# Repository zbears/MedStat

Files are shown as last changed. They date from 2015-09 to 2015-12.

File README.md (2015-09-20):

# MedStat
A wearable medical wristband

## Eagle Setup
In order to modify the cirucits in Eagle, clone the git repo then open Eagle. Go to Options->Directories and add the /circuits/libraries folder to your libraries path. Then add the /circuits folder to your projects path.

## Creating/Modifying Circuits
To create or modify a circuit, please create a separate branch from master. Go into the /circuits folder and create a directory whose name corresponds to the circuit you are creating. When you've finished creating the circuit, submit a pull request and have your circuit verified by one engineer. Once the circuit is verified, make the modifications to the main MedStat eagle project to include your circuit, submit another pull request to master, have one other engineer verify your circuit, then merge your branch with master. Do not delete your branch after merging with master.

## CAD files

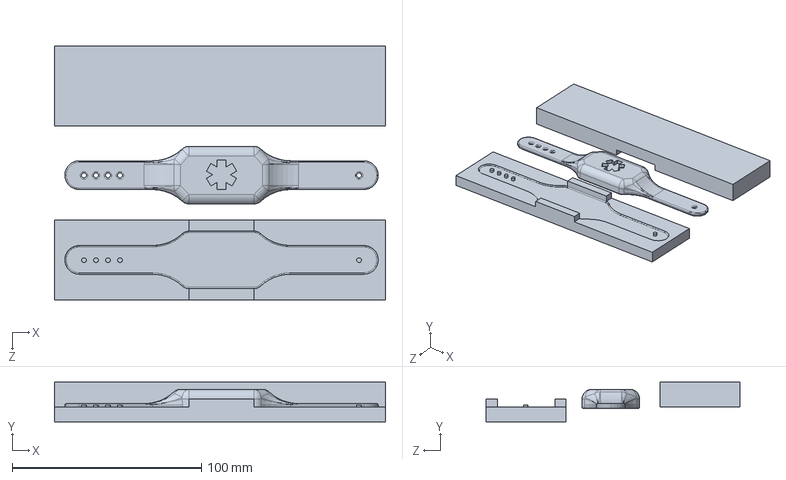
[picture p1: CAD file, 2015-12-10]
3d models/Wristband.SLDPRT
175.1 x 21.1 x 134.4 mm

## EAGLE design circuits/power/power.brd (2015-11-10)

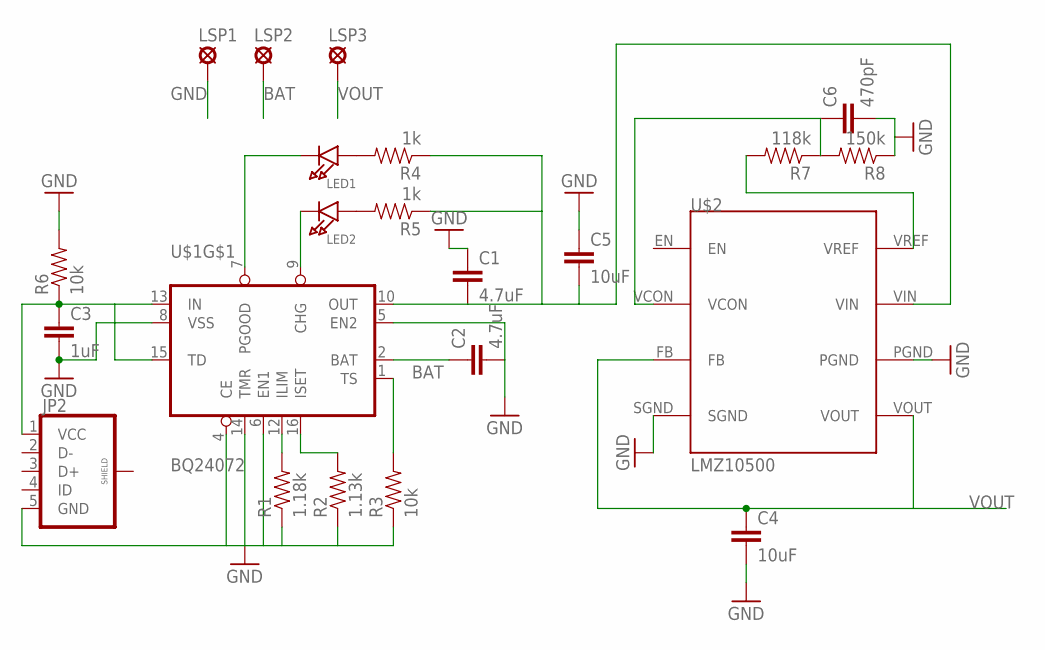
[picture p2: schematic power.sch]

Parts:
C1, C2: 4.7uF; 0603-CAP
C3: 1uF; 0603-CAP
C4, C5: 10uF; 0603-CAP
C6: 470pF; 0603-CAP
JP2: USB_MICROB_PLUG-SMT; MICRO-B-SMT
LED1, LED2: LED0603; CHIPLED_0603
LSP1, LSP2, LSP3: LSP10
R1: 1.18k; 0603-RES
R2: 1.13k; 0603-RES
R3, R6: 10k; 0603-RES
R4, R5: 1k; 0603-RES
R7: 118k; 0603-RES
R8: 150k; 0603-RES
U$1: BQ24072; S-PVQFN-N16
U$2: LMZ10500

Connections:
BAT: C2.1, LSP2.MP, U$1.2 (BAT)
GND: C1.1, C2.2, C3.2, C4.2, C5.1, C6.2, JP2.5 (GND), LSP1.MP, R1.1, R2.1, R3.1, R6.2, R8.1, U$1.4 (CE), U$1.5 (EN2), U$1.6 (EN1), U$1.8 (VSS), U$1.14 (TMR), U$2.PGND, U$2.SGND
unnamed: R7.2, U$2.VREF
unnamed: C6.1, R7.1, R8.2, U$2.VCON
unnamed: R1.2, U$1.12 (ILIM)
unnamed: R2.2, U$1.16 (ISET)
unnamed: R3.2, U$1.1 (TS)
unnamed: C1.2, C5.2, R4.1, R5.1, U$1.10 (OUT), U$2.VIN
unnamed: LED1.A, R4.2
unnamed: LED2.A, R5.2
unnamed: LED2.C, U$1.9 (CHG)
unnamed: LED1.C, U$1.7 (PGOOD)
unnamed: C3.1, JP2.1 (VCC), R6.1, U$1.13 (IN), U$1.15 (TD)
VOUT: C4.1, LSP3.MP, U$2.FB, U$2.VOUT

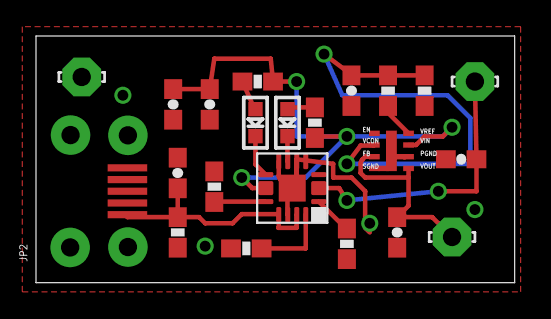
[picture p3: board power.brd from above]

Board: 2 copper layers, 26.6 x 13.7 mm, 22 parts (0 on the bottom side), 14 nets.

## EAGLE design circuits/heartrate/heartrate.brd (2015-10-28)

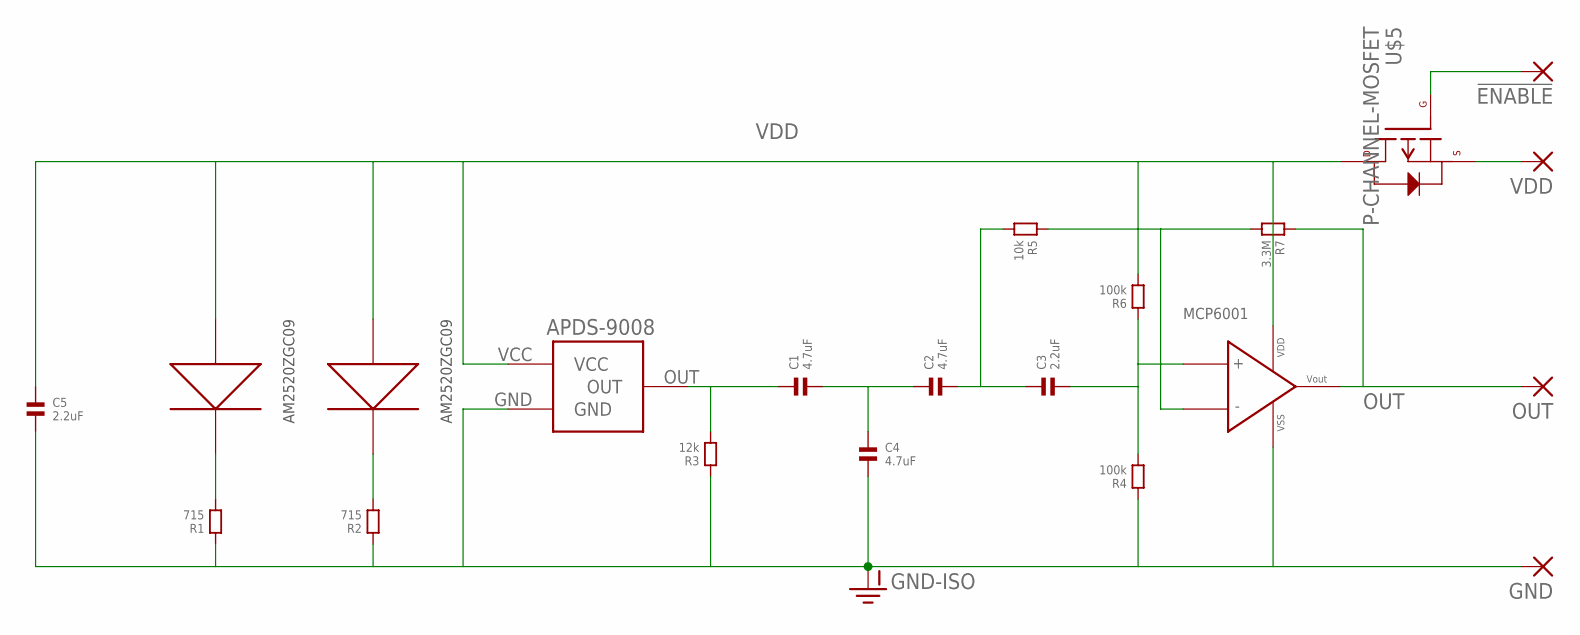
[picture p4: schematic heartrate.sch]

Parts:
!ENABLE: SMD2; SMD1,27-2,54
C1, C2, C4: 4.7uF; 0402
C3, C5: 2.2uF; 0402
GND: SMD2; SMD1,27-2,54
OUT: SMD2; SMD1,27-2,54
R1, R2: 715; 0402
R3: 12k; 0402
R4, R6: 100k; 0402
R5: 10k; 0402
R7: 3.3M; 0402
U$1, U$2: DSAH3717
U$3: APDS-9008
U$4: MCP6001; SOT23-5
U$5: P-CHANNEL-MOSFET; SOT23-3
VDD: SMD2; SMD1,27-2,54

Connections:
GND: C4.2, C5.2, GND.1, R1.1, R2.1, R3.1, R4.1, U$3.GND, U$4.VSS
unnamed: R1.2, U$1.G (GND)
unnamed: U$5.2 (S), VDD.1
unnamed: !ENABLE.1, U$5.1 (G)
unnamed: R2.2, U$2.G (GND)
unnamed: C1.1, R3.2, U$3.OUT
unnamed: C1.2, C2.1, C4.1
unnamed: C2.2, C3.1, R5.2
unnamed: C3.2, R4.2, R6.1, U$4.VIN+
unnamed: R5.1, R7.2, U$4.VIN-
OUT: OUT.1, R7.1, U$4.VOUT
VDD: C5.1, R6.2, U$1.V (VDD), U$2.V (VDD), U$3.VCC, U$4.VDD, U$5.3 (D)

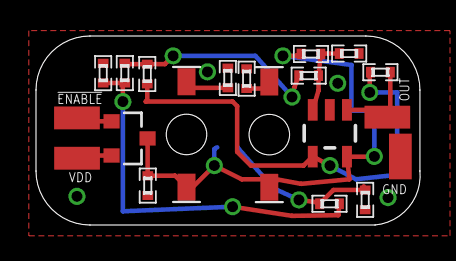
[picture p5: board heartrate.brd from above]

Board: 2 copper layers, 21.3 x 10.5 mm, 21 parts (1 on the bottom side), 12 nets.

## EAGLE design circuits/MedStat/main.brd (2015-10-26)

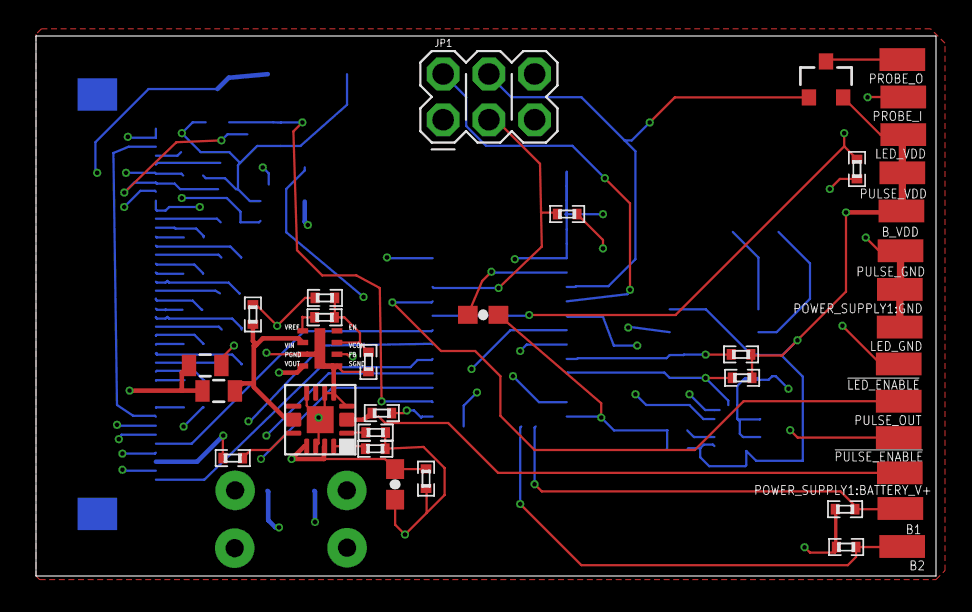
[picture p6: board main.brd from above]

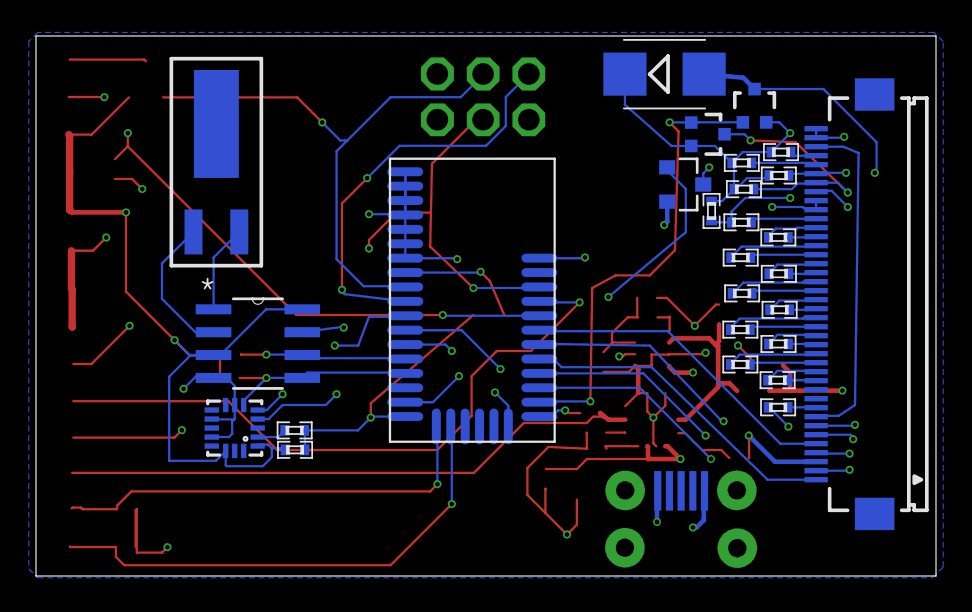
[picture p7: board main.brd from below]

Board: 4 copper layers, 50.0 x 30.0 mm, 65 parts (28 on the bottom side), 60 nets.

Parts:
!LED_ENABLE: SMD1,27-2,54
!PULSE_ENABLE: SMD1,27-2,54
B1, B2: SMD1,27-2,54
B_VDD: SMD1,27-2,54
C1: 1uF; 0603-CAP
C2: 0.1uF; 0402
C3: 4.7uF; 0402
EPAPER_DRIVER1:C1, EPAPER_DRIVER1:C2, EPAPER_DRIVER1:C3, EPAPER_DRIVER1:C4, EPAPER_DRIVER1:C5, EPAPER_DRIVER1:C6, EPAPER_DRIVER1:C7, EPAPER_DRIVER1:C8, EPAPER_DRIVER1:C9, EPAPER_DRIVER1:C10, EPAPER_DRIVER1:C12, EPAPER_DRIVER1:C13, EPAPER_DRIVER1:C14, EPAPER_DRIVER1:C15: 2.2uF; 0402
EPAPER_DRIVER1:C11: 1uF; 0402
EPAPER_DRIVER1:D2: B24013F; SMB
EPAPER_DRIVER1:Q1, EPAPER_DRIVER1:Q2: MOSFET-NCHANNEL2N7002PW; SOT323
EPAPER_DRIVER1:R1: 2k; 0402
EPAPER_DRIVER1:U$1: P-CHANNEL-MOSFET; SOT23-3
EPAPER_DRIVER1:X1: FH12-40S-0.5SH
JP1: 2X3_POGO
LED_GND: SMD1,27-2,54
LED_VDD: SMD1,27-2,54
POWER_SUPPLY1:BATTERY_V+, POWER_SUPPLY1:GND: SMD1,27-2,54
POWER_SUPPLY1:C1, POWER_SUPPLY1:C4: 4.7uF; 0402
POWER_SUPPLY1:C2, POWER_SUPPLY1:C3: 10uF; 0805
POWER_SUPPLY1:C6: 470pF; 0402
POWER_SUPPLY1:C7: 1uF; 0603-CAP
POWER_SUPPLY1:JP1: MICRO-B-SMT
POWER_SUPPLY1:R1: 1.18k; 0402
POWER_SUPPLY1:R2: 1.13k; 0402
POWER_SUPPLY1:R3, POWER_SUPPLY1:R4: 10k; 0402
POWER_SUPPLY1:R5: 150k; 0402
POWER_SUPPLY1:R6: 118k; 0402
POWER_SUPPLY1:U$1: BQ24072; S-PVQFN-N16
POWER_SUPPLY1:U$2: LMZ10500
PROBE_I: SMD1,27-2,54
PROBE_O: SMD1,27-2,54
PULSE_GND: SMD1,27-2,54
PULSE_OUT: SMD1,27-2,54
PULSE_VDD: SMD1,27-2,54
R1, R5, R6: 10k; 0402
R2, R3: 4.7k; 0402
R4: 1M; 0402
U1: BLE113-A
U2: MMA8452Q; QFN-16_0.5MM
U3: BQ32000DR; SOIC127P600X175-8N
U$1: P-CHANNEL-MOSFET; SOT23-3
Y1: CRYSTAL_CYL_2X6MM_SMT

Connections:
3.3V: B_VDD.1, C1.2, C3.1, EPAPER_DRIVER1:U$1.2, JP1.P$1, LED_VDD.1, POWER_SUPPLY1:C2.1, POWER_SUPPLY1:U$2.FB, POWER_SUPPLY1:U$2.VOUT, PULSE_VDD.1, R1.2, R2.2, R3.2, U1.AVDD, U1.DVDD, U2.1, U2.14, U3.3, U3.8, U$1.2
!RESET: JP1.P$3, R1.1, U1.RESET
EPAPER_DRIVER1:BORDER: EPAPER_DRIVER1:X1.8, EPAPER_DRIVER1:X1.38
EPAPER_DRIVER1:C11M: EPAPER_DRIVER1:C10.2, EPAPER_DRIVER1:X1.28
EPAPER_DRIVER1:C11P: EPAPER_DRIVER1:C10.1, EPAPER_DRIVER1:X1.29
EPAPER_DRIVER1:C12M: EPAPER_DRIVER1:C9.2, EPAPER_DRIVER1:X1.26
EPAPER_DRIVER1:C12P: EPAPER_DRIVER1:C9.1, EPAPER_DRIVER1:X1.27
EPAPER_DRIVER1:C13M: EPAPER_DRIVER1:C8.2, EPAPER_DRIVER1:X1.24
EPAPER_DRIVER1:C13P: EPAPER_DRIVER1:C8.1, EPAPER_DRIVER1:X1.25
EPAPER_DRIVER1:C14M: EPAPER_DRIVER1:C7.2, EPAPER_DRIVER1:X1.22
EPAPER_DRIVER1:C14P: EPAPER_DRIVER1:C7.1, EPAPER_DRIVER1:X1.23
EPAPER_DRIVER1:C15M: EPAPER_DRIVER1:C6.2, EPAPER_DRIVER1:X1.20
EPAPER_DRIVER1:C15P: EPAPER_DRIVER1:C6.1, EPAPER_DRIVER1:X1.21
EPAPER_DRIVER1:C16M: EPAPER_DRIVER1:C5.2, EPAPER_DRIVER1:X1.18
EPAPER_DRIVER1:C16P: EPAPER_DRIVER1:C5.1, EPAPER_DRIVER1:X1.19
EPAPER_DRIVER1:C21M: EPAPER_DRIVER1:C4.2, EPAPER_DRIVER1:X1.16
EPAPER_DRIVER1:C21P: EPAPER_DRIVER1:C4.1, EPAPER_DRIVER1:X1.17
EPAPER_DRIVER1:C31M: EPAPER_DRIVER1:C3.2, EPAPER_DRIVER1:X1.14
EPAPER_DRIVER1:C31P: EPAPER_DRIVER1:C3.1, EPAPER_DRIVER1:X1.15
EPAPER_DRIVER1:C32M: EPAPER_DRIVER1:C2.2, EPAPER_DRIVER1:X1.12
EPAPER_DRIVER1:C32P: EPAPER_DRIVER1:C2.1, EPAPER_DRIVER1:X1.13
EPAPER_DRIVER1:E_VDD: EPAPER_DRIVER1:U$1.3, EPAPER_DRIVER1:X1.31, EPAPER_DRIVER1:X1.32
EPAPER_DRIVER1:VCL: EPAPER_DRIVER1:C1.2, EPAPER_DRIVER1:X1.9
EPAPER_DRIVER1:VCOM_DRIVER: EPAPER_DRIVER1:R1.2, EPAPER_DRIVER1:X1.30
EPAPER_DRIVER1:VDH: EPAPER_DRIVER1:C14.2, EPAPER_DRIVER1:X1.36
EPAPER_DRIVER1:VDL: EPAPER_DRIVER1:C15.2, EPAPER_DRIVER1:X1.37
EPAPER_DRIVER1:VGH: EPAPER_DRIVER1:C12.2, EPAPER_DRIVER1:Q2.3, EPAPER_DRIVER1:X1.34
EPAPER_DRIVER1:VGL: EPAPER_DRIVER1:C13.2, EPAPER_DRIVER1:D2.A, EPAPER_DRIVER1:Q1.3, EPAPER_DRIVER1:X1.35
EPAPER_DRIVER1:VST: EPAPER_DRIVER1:C11.2, EPAPER_DRIVER1:R1.1, EPAPER_DRIVER1:X1.39, EPAPER_DRIVER1:X1.40
GND: C1.1, C2.1, C3.2, EPAPER_DRIVER1:C1.1, EPAPER_DRIVER1:C11.1, EPAPER_DRIVER1:C12.1, EPAPER_DRIVER1:C13.1, EPAPER_DRIVER1:C14.1, EPAPER_DRIVER1:C15.1, EPAPER_DRIVER1:D2.C, EPAPER_DRIVER1:Q1.2, EPAPER_DRIVER1:Q2.2, EPAPER_DRIVER1:X1.3, EPAPER_DRIVER1:X1.33, JP1.P$5, LED_GND.1, POWER_SUPPLY1:C1.1, POWER_SUPPLY1:C2.2, POWER_SUPPLY1:C3.2, POWER_SUPPLY1:C4.1, POWER_SUPPLY1:C6.1, POWER_SUPPLY1:C7.2, POWER_SUPPLY1:GND.1, POWER_SUPPLY1:JP1.5, POWER_SUPPLY1:R1.1, POWER_SUPPLY1:R2.1, POWER_SUPPLY1:R3.1, POWER_SUPPLY1:R4.1, POWER_SUPPLY1:R5.1, POWER_SUPPLY1:U$1.4, POWER_SUPPLY1:U$1.5, POWER_SUPPLY1:U$1.6, POWER_SUPPLY1:U$1.8, POWER_SUPPLY1:U$1.14, POWER_SUPPLY1:U$2.PGND, POWER_SUPPLY1:U$2.SGND, PULSE_GND.1, R4.2, R5.1, R6.1, U1.GND, U1.GND@2, U1.GND@3, U1.GND@4, U1.GND@5, U1.GND@6, U1.GND@7, U1.GND@8, U1.GND@9, U1.GND@10, U2.5, U2.7, U2.10, U2.12, U3.4
unnamed: U3.2, Y1.2
unnamed: C2.2, U2.2
unnamed: PROBE_O.1, U$1.3
OSCI: U3.1, Y1.1
P0_0: PULSE_OUT.1, U1.P0_0
P0_1: PROBE_I.1, R4.1, U1.P0_1
P0_2: EPAPER_DRIVER1:X1.5, U1.P0_2
P0_3: EPAPER_DRIVER1:X1.6, U1.P0_3
P0_4: EPAPER_DRIVER1:X1.1, U1.P0_4
P0_5: EPAPER_DRIVER1:X1.4, U1.P0_5
P0_6: EPAPER_DRIVER1:X1.2, U1.P0_6
P0_7: EPAPER_DRIVER1:Q1.1, EPAPER_DRIVER1:Q2.1, U1.P0_7
P1_0: U1.P1_0, U3.7
P1_4: B2.1, R6.2, U1.P1_4
P1_5: B1.1, R5.2, U1.P1_5
P1_6: EPAPER_DRIVER1:U$1.1, U1.P1_6
P1_7: EPAPER_DRIVER1:X1.7, U1.P1_7
P2_0: !PULSE_ENABLE.1, U1.P2_0
P2_1: !LED_ENABLE.1, JP1.P$2, U1.P2_1
P2_2: JP1.P$4, U1.P2_2, U$1.1
POWER_SUPPLY1:BATTERY_V+: POWER_SUPPLY1:BATTERY_V+.1, POWER_SUPPLY1:C1.2, POWER_SUPPLY1:U$1.2
POWER_SUPPLY1:CHG_OUT: POWER_SUPPLY1:C3.1, POWER_SUPPLY1:C4.2, POWER_SUPPLY1:U$1.10, POWER_SUPPLY1:U$2.VIN
POWER_SUPPLY1:N$1: POWER_SUPPLY1:C6.2, POWER_SUPPLY1:R5.2, POWER_SUPPLY1:R6.1, POWER_SUPPLY1:U$2.VCON
POWER_SUPPLY1:N$2: POWER_SUPPLY1:R6.2, POWER_SUPPLY1:U$2.VREF
POWER_SUPPLY1:N$3: POWER_SUPPLY1:R2.2, POWER_SUPPLY1:U$1.16
POWER_SUPPLY1:N$5: POWER_SUPPLY1:R1.2, POWER_SUPPLY1:U$1.12
POWER_SUPPLY1:N$7: POWER_SUPPLY1:R3.2, POWER_SUPPLY1:U$1.1
POWER_SUPPLY1:VCC: POWER_SUPPLY1:C7.1, POWER_SUPPLY1:JP1.1, POWER_SUPPLY1:R4.2, POWER_SUPPLY1:U$1.13, POWER_SUPPLY1:U$1.15
SCL: R2.1, U1.SCL, U2.4, U3.6
SDA: R3.1, U1.SDA, U2.6, U3.5

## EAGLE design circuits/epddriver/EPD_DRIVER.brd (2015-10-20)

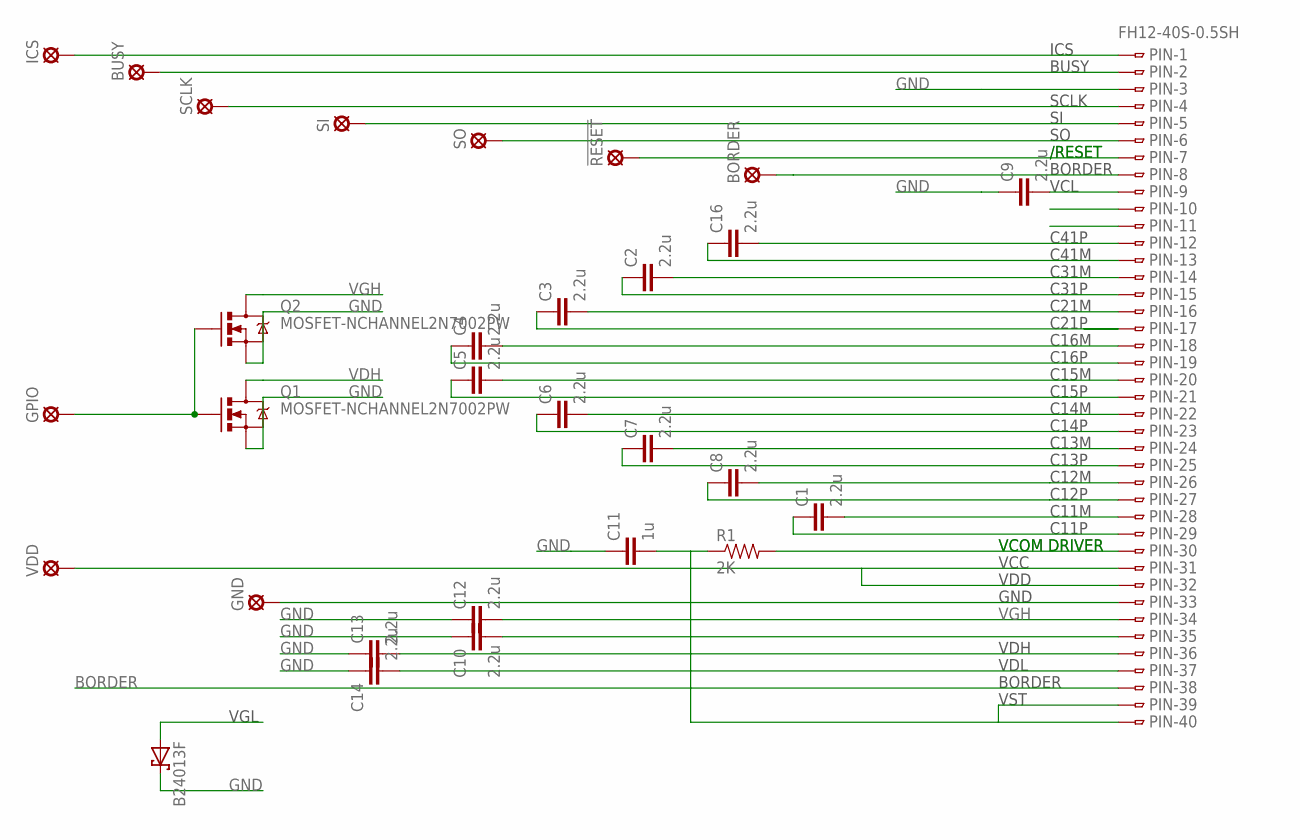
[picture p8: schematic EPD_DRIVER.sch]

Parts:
!RESET: SE11
B24013F: SCHOTTKY-DIODESMD; SMB
BORDER: SE11
BUSY: SE11
C1, C2, C3, C4, C5, C6, C7, C8, C9, C10, C12, C13, C14, C16: 2.2u; 0603-CAP
C11: 1u; 0603-CAP
GND: SE11
GPIO: SE11
ICS: SE11
PIN: FH12-40S-0.5SH
Q1, Q2: MOSFET-NCHANNEL2N7002PW; SOT323
R1: 2K; 0603-RES
SCLK: SE11
SI: SE11
SO: SE11
VDD: SE11

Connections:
BORDER: BORDER.MP, PIN.8, PIN.38
GND: B24013F.C, C9.1, C10.1, C11.1, C12.1, C13.1, C14.1, PIN.3, Q1.2 (S), Q2.2 (S)
ICS: ICS.MP, PIN.1
unnamed: PIN.4, SCLK.MP
unnamed: BUSY.MP, PIN.2
unnamed: PIN.5, SI.MP
unnamed: PIN.6, SO.MP
unnamed: !RESET.MP, PIN.7
unnamed: GND.MP, PIN.33
unnamed: C16.2, PIN.12
unnamed: C16.1, PIN.13
unnamed: C2.2, PIN.14
unnamed: C2.1, PIN.15
unnamed: C3.2, PIN.16
unnamed: C3.1, PIN.17
unnamed: C4.2, PIN.18
unnamed: C4.1, PIN.19
unnamed: C5.2, PIN.20
unnamed: C5.1, PIN.21
unnamed: C6.2, PIN.22
unnamed: C6.1, PIN.23
unnamed: C7.2, PIN.24
unnamed: C7.1, PIN.25
unnamed: C8.2, PIN.26
unnamed: C8.1, PIN.27
unnamed: C1.2, PIN.28
unnamed: C1.1, PIN.29
unnamed: PIN.30, R1.2
unnamed: PIN.31, PIN.32, VDD.MP
unnamed: GPIO.MP, Q1.1 (G), Q2.1 (G)
VCL: C9.2, PIN.9
VDH: C13.2, PIN.36, Q1.3 (D)
VDL: C14.2, PIN.37
VGH: C10.2, PIN.34, Q2.3 (D)
VGL: B24013F.A, C12.2, PIN.35
VST: C11.2, PIN.39, PIN.40, R1.1

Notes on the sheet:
ICS
BUSY
SCLK
/RESET
BORDER
VCL
C41P
C41M
C31M
C31P
C21M
C21P
C16M
C16P
C15M
C15P
C14M
C14P
C13M
C13P
C12M
C12P
C11M
C11P
VCOM DRIVER
VCC
VDD
GND
VDH
VDL
VST
VGL

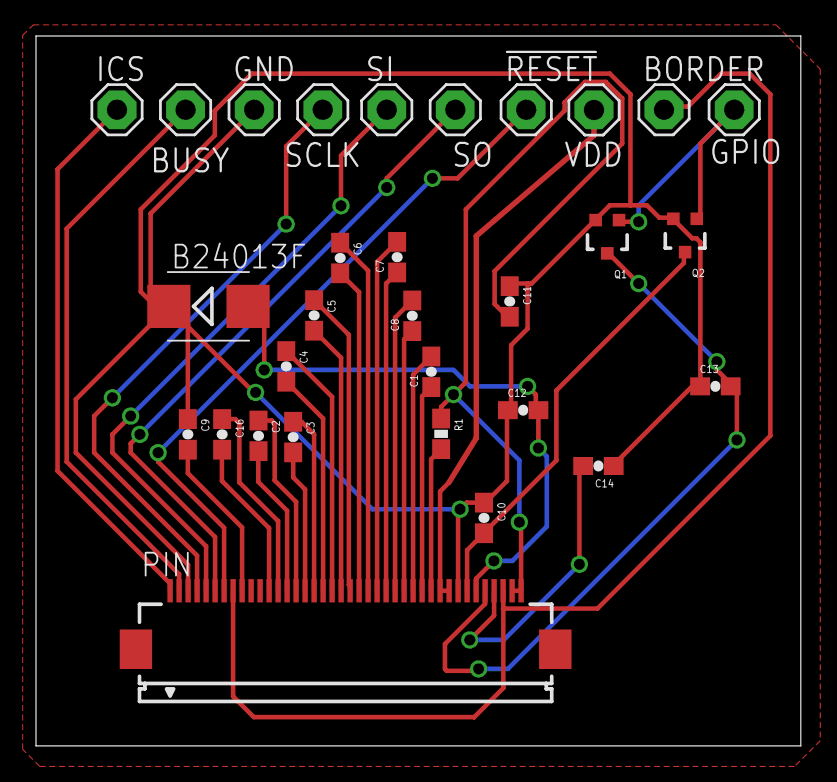
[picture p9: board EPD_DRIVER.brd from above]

Board: 2 copper layers, 42.5 x 39.4 mm, 30 parts (0 on the bottom side), 36 nets.

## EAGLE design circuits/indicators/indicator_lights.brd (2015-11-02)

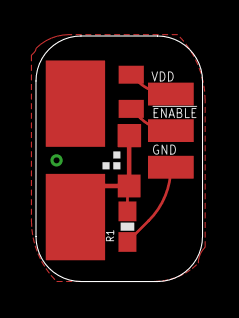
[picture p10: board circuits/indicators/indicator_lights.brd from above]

Board: 2 copper layers, 9.3 x 13.6 mm, 6 parts (0 on the bottom side), 5 nets.

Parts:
!ENABLE: SMD1,27-2,54
GND: SMD1,27-2,54
LED1: LS E67B; P-LCC-4-3
Q1: BSS84; SOT23
R1: 36; 0603-RES
VDD: SMD1,27-2,54

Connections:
!ENABLE: !ENABLE.1, Q1.1
GND: GND.1, R1.1
unnamed: LED1.2, Q1.3
unnamed: LED1.1, LED1.3, LED1.4, R1.2
VDD: Q1.2, VDD.1

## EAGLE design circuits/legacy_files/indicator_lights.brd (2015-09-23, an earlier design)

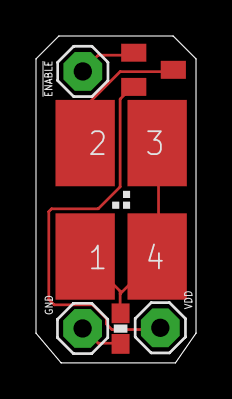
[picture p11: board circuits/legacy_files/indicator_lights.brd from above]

Board: 2 copper layers, 8.9 x 18.2 mm, 6 parts (0 on the bottom side), 5 nets.

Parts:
LED1: LS E67B; P-LCC-4-3
LSP1, LSP2, LSP3: MCS10B
Q1: BSS84; SOT23
R1: 36; 0603-RES

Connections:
!ENABLE: LSP1.MP, Q1.1
GND: LSP3.MP, R1.1
unnamed: LED1.2, Q1.3
unnamed: LED1.1, LED1.3, LED1.4, R1.2
VDD: LSP2.MP, Q1.2

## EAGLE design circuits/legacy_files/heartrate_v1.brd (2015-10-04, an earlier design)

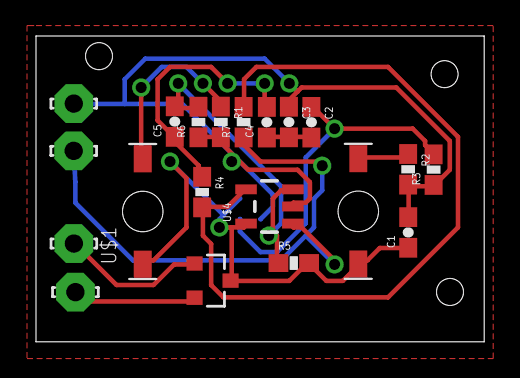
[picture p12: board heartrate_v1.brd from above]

Board: 2 copper layers, 24.9 x 17.0 mm, 21 parts (1 on the bottom side), 12 nets.

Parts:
!ENABLE: LSP10
C1: 2.2uF; 0603-CAP
C2, C3, C4: 4.7 uF; 0603-CAP
C5: 2.2 uF; 0603-CAP
GND: LSP10
OUT: LSP10
R1, R2: 715; 0603-RES
R3: 12k; 0603-RES
R4: 10k; 0603-RES
R5, R6: 100k; 0603-RES
R7: 3.3M; 0603-RES
U$1, U$2: DSAH3717
U$3: APDS-9008
U$4: MCP6001; SOT23-5
U$5: P-CHANNEL-MOSFET; SOT23-3
VDD: LSP10

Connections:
GND-ISO: C1.2, C3.1, GND.MP, R1.2, R2.2, R3.1, R6.1, U$3.GND, U$4.VSS
unnamed: R1.1, U$1.G
unnamed: U$5.2, VDD.MP
unnamed: !ENABLE.MP, U$5.1
unnamed: R2.1, U$2.G
unnamed: C2.1, R3.2, U$3.OUT
unnamed: C2.2, C3.2, C4.1
unnamed: C4.2, C5.1, R4.1
unnamed: C5.2, R5.1, R6.2, U$4.VIN+
unnamed: R4.2, R7.2, U$4.VIN-
OUT: OUT.MP, R7.1, U$4.VOUT
VDD: C1.1, R5.2, U$1.V, U$2.V, U$3.VCC, U$4.VDD, U$5.3

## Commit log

2015-09-20 Create README.md
    Added guidelines for creating+modifying circuits
2015-09-20 Added custom through-hole LED schematic
2015-09-21 Added pulse sensing circuitry
    [heartrate.sch]
2015-09-21 Added accelerometer circuit
    [heartrate.sch, main.sch]
2015-09-23 Created indicator schematic+board
    [indicator_lights.brd, indicator_lights.sch]
2015-09-23 Added a driver circuit meant to interface with the 1.44' EPD.
    [EPD_DRIVER.sch]
2015-10-04 Integrated LED pins with main schematic
    [main.sch]
2015-10-04 Created pulse sensor layout
    [heartrate.brd, heartrate.sch]
2015-10-04 Tied in moisture sensor pins
2015-10-04 Added pulse sensor ports
    [main.sch]
2015-10-10 created new power circuit in different branch and folder
    [power.sch]
2015-10-10 made custom file and added buck converter into circuit
2015-10-12 Integrated EPD driver to main schematic.
    [main.sch]
2015-10-14 Added Blink Sketch
    Added a sketch that makes the BLE113 blink an LED on pin P0_0 on a 1s
    interval
2015-10-16 Integrated EPD into main schematic.
    [main.sch]
2015-10-18 fixed the footprint of the buck converter
2015-10-20 Fixed EPD_DRIVER schematic and created layout for it
    [EPD_DRIVER.brd, EPD_DRIVER.sch]
2015-10-21 added power circuit to main schematic
    [main.sch]
2015-10-23 finished layout of power circuit
    [power.brd]
2015-10-23 added pull up resistor to reset button
    [main.sch]
2015-10-25 branch create
    [main_old.sch]
2015-10-25 Added in revised power circuit layout
    [main.sch]
2015-10-25 changed resistor and capacitor sizes
    [heartrate.sch, heartrate_v1.brd]
2015-10-26 Completed master schematic
    [main.sch]
2015-10-26 Finished final board layout round 1
    [main.brd, main.sch]
2015-10-26 finished new heart rate sensor layout
    [heartrate.brd, heartrate.sch]
2015-10-27 remade heart rate sensor
    [heartrate_v2.brd]
2015-10-28 deleted dimension lines from heart sensor layout
    [heartrate.brd]
2015-11-02 Added LED blinking VIA BLE control
    A LED attached to P0_0 now illuminates when a connection is made with
    the module and a LED on pin P0_1 can be toggled on and off by sending a
    1 or a 0 byte to the LED toggle service.
2015-11-02 Cleaned up code + Added accelerometer
    Removed some currently unneeded features so @Millerj1994 will have to
    add back in pulse timers when merging. I can help you with this.
2015-11-02 Added new LED layout
    [indicator_lights.brd]
2015-11-10 changed LMZ10500 library. updated power schematic and switched out usb. Made new power layout.
    [power.brd, power.sch, power_v1.brd]
2015-11-10 made power board ready for order. Want to check with zach
    [power.brd]
2015-12-10 Final Code and Rough 3D
    [Wristband.SLDPRT]

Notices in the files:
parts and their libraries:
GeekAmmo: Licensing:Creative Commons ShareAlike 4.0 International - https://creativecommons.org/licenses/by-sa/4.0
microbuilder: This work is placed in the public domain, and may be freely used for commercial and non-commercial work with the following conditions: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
